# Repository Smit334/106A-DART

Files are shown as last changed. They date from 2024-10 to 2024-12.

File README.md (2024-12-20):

# 106A-DART

Our project aims to develop a transformable robotic vehicle that can transform from a car to a drone. It will achieve this by rotating the wheels 90 degrees and take flight using built-in propellers. It will be equipped with ultrasonic sensors to detect obstacles in its path, and navigate around them, either by maneuvering on the ground or flying over it. This innovative design offers the potential for enhanced mobility and versatility in various applications, such as search and rescue operations, exploration, and package delivery. 

## Repository Structure
- `docs`: writeups and presentations
- `ecad`: remote and vehicle PCB design files (Altium)
- `firmware`: remote and vehicle embedded code
- `mcad`: mechanical CAD, in .STEP format

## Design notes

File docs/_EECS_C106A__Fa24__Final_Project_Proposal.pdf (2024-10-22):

## EECS/BioE/MechE 106A/206A D.A.R.T: Driving And Rising Technology

Fall 2024

## 1 Team Information

Name | Background
Smit | Smit is a 4th year EECS major interested in Power Electronics, EV and Energy systems, electronics hardware design, and some firmware.
Amal | Amal is a 4th year EECS major interested in electronics and hardware design, pcb design, and robotics.
Nikhil | Nikhil is a 4th year EECS major interested in low-level programming, computerized systems infrastructure, and HV system design.
Andrew | Andrew is a 3rd Year Aerospace Engineering and EECS double major, interested in robotics, mechanical and electrical HW.
Mary | Mary is a 4th year EECS and Bioengineering double major interested in computer architecture and hardware design.

## 2 Abstract

Our project aims to develop a transformable robotic vehicle that can transform from a car to a drone. It will achieve this by rotating the wheels 90 degrees and take flight using built-in propellers. It will be equipped with ultrasonic sensors to detect obstacles in its path, and navigate around them, either by maneuvering on the ground or flying over it. This innovative design offers the potential for enhanced mobility and versatility in various applications, such as search and rescue operations, surveillance, and package delivery.

## 3 Project Description

### 3.1 Project Goals

What are your project goals?

- Successful Transformation: Develop a mechanism that allows the vehicle to reliably transform between car and drone configurations.
- Obstacle Detection and Avoidance: Implement an effective obstacle detection system using ultrasonic sensors to enable the vehicle to navigate around obstacles both on the ground and in the air through sensing and planning.
- Optimization: utilize weight-saving methods and implement power optimization to ensure the robot is as efficient as possible to maximize operation time.

### 3.2 Project Architecture

DART’s Hardware and Software systems will work together to meet project goals specified in section 3.1.

### 3.2.1 Software

- ROS: Using ROS Client/Server or Subscriber Publisher, to communicate sensor information to the micro controller to make high-level decisions for e.g if DART should be in drive mode or fly mode. And for the motor controllers to make more fine decisions like controlling power to each motor.
- Communication Protocols: We have the architecture for ROS setup as mentioned above but we will use some protocols to communicate this information on the firmware level. Some protocols we may use include:

– SPI
– I2C
– UART
– Analog and PWM
- Object detection libraries - to use information from the camera and Distance sensors to map objects and make decisions to avoid them.
- Autonomous and Remote Operation Modes

– Remote Operation: Radio-controlled mode will allow an operator to manually control the robot’s movement and transformation.
– Pre-programmed Path Execution: Users can define paths using way-points; the software will switch modes (drive/fly) as needed along the route
- Control Loops: PID Controllers will manage the speed of motors for smooth driving and flight stability

### 3.2.2 Hardware

The system will consist of the following subsystems

- Computing Subsystem: Responsible for coordinating and controlling other subsystems.

– Remote Operation: executes commands transmitted over the communication subsystem, interrupting them when necessary based on sensor subsystem feedback.
– Autonomous Operation: executes pre-programmed commands while reacting to feedback from the sensor subsystem.
- Power Distribution Subsystem: Responsible for ensuring sufficient power is provided to all subsystems when needed.
- Sensor Subsystem: Responsible for providing information about the robot’s local environment; detecting obstacles, mapping surroundings, etc. Consists of the following sensors:

– Digital Camera
– Distance Sensors
– IMU (Inertial Measurement Unit)
- Communication Subsystem:

– Remote Operation: Receives command inputs, transmits sensor information and other subsystem data.
– Autonomous Operation: Transmits sensor information, and other subsystem data.
- Flying Subsystem: Consists of a set of 4 motors in a quad-copter configuration. Works with the computing subsystem and sensor subsystem to fly in the air.
- Driving Subsystem: Consists of a set of 4 motors to drive on the ground.
- Transformation Subsystem: Responsible for transitioning between the flying and driving configurations of the robot.

### 3.3 Project Sensing, Planning, and Actuation

How does your project incorporate sensing, planning, and actuation?
Sensing:
- Drive Mode: Sensors like LiDAR or ultrasonic sensors will be used to detect obstacles, focusing on the vertical axis in front of the robot. These sensors will determine the height of obstacles and detect when they become unavoidable.
- Flight Mode: The same sensors will monitor the height and proximity of obstacles, determining how high the drone needs to fly to clear them. Additionally, these sensors will identify when the obstacle has been cleared, allowing the robot to safely return to the ground. Sensors will monitor the terrain below during flight to detect when it is safe to land (e.g., flat surface or low obstacle height).

Planning:

- Drive Mode: The robot will follow a pre-specified path or respond to remote control inputs for direction. While navigating, the robot will analyze the sensor data to detect obstacles in its path. If an obstacle is too tall to drive over or around, the robot’s planning system will trigger a transition to flight mode.
- Flight Navigation: The planning system will use obstacle height data to calculate the necessary altitude for the drone to fly over the obstacle safely. The system will continuously monitor the vertical space until it senses that the obstacle has been passed and there’s a clear landing zone. Once the planning system detects that the obstacle is behind the robot and that it can safely descend, it will initiate the transition back to drive navigation, allowing the robot to resume following the path or remote control directions.

Actuation:

- Drive Mode: The robot’s drive motors will actuate based on planned paths or remote control inputs. When the system senses an unavoidable obstacle, the robot will stop moving, preparing for transition into flight mode.
- Flight Mode: The robot will actuate propeller motors to take off and adjust its altitude based on the calculated obstacle height. The actuation system will maintain flight until the obstacle is passed, at which point the descent will be triggered. The actuation system will control the drone’s descent once the terrain below is deemed safe for landing, switching back to drive mode.

### 3.4 Project Tests and Metrics

How will you test or assess your project? What constitutes a success? What are some realistic goals? What are some reach goals?
This project is intended as mainly a proof-of-concept. That is, a successful project will involve basic testing of the robot’s core functions. Enumerated, these are:
- Motor control: Drive all motors simultaneously at varying speeds using the MCU. This validates the motors are functional, the MCU can send commands, and the power delivery system to the motors is adequately sized.
- Communication: Drive one or more motors over the radio control system, testing the radio. Repeat this test for multiple ranges to find a maximum radio communication distance.
- Basic driving: The robot drives a short distance without flying, from commands issued through the radio controller.
- Basic flying: The robot flies a short distance (take off, hover, rotate, directional translation, and landing) without driving from commands issued through the radio controller.

- Drive → Fly transition: Start by driving, transition to flying, and end by flying.
- Fly → Drive transition: Start by flying, transition to driving, and end by driving.
- Pre-programmed path execution: Send a path to the vehicle from the base station with instructions to drive/fly a certain distance, then execute those instructions with reasonable accuracy.
- Driving with sensing: Drive with automatic object avoidance
- Flying with sensing: Fly with automatic object avoidance

These are all reasonable goals which should be able to be completed within the given time window. A stretch goal would be to implement an automatic fly/drive transition feature, where the vehicle could transform from flying to driving mode (or vice versa) based on the environment in order to avoid obstacles. A test for this may be a set of stairs, in which the vehicle would detect the stairs and transition to flying mode to avoid said stairs by going over them.

## 4 Tasks

Here, list out different major and minor tasks of the project, along with when you plan to achieve them. Keep in mind the checkpoint dates (11/9 and 11/29). For example,

1. Build the robot
(a) Design the Robot [by 11/2]
i. Design the Robot Frame [by 11/2]
A. Design the Transformation Subsystem Emphasis is put on ensuring a sound transformation system is designed, other parts of the frame are dependent this design.[by 11/1]
B. Design Other Robot Structural Components Ensure the system is structurally sound in both modes of operation, plan out the placement of electronics. [by 11/1]
ii. Design the Robot Electronics [by 11/2]
A. Select Necessary Parts Spec out the exact components used for the robot, crucial to determining other aspects of design. [by 10/26]
B. Design the Central PCB Based on component specifications, incorporate Power Distribution, Computing, Communication, and Sensor subsystems onto a unified PCB. [by 11/2]
(b) Assemble the Robot [by 11/11]
i. If any issues are encountered in this stage, rapid prototyping will modify the design.
2. Code the robot. We will program the robot using C++, Python, Arduino
(a) Develop firmware for peripherals listed below [by 11/6]
i. IMU
ii. Motor controller
iii. Servo controller
iv. Camera and Distance sensors
(b) Develop ROS Nodes : Controller and sensor nodes to broadcast information [by 11/13]
(c) Develop Software/firmware for controlling DART in Remote mode [by 11/25]
(d) Object detection and path planning algorithm: Working in parallel to Firmware development to design the autonomous planning. [by 11/25]
3. Testing

(a) Hardware Validation Ensure all the hardware is working as expected, without direct software control from intended controller system [by 11/17]
(b) Software Validation Ensure software is functioning without intended hardware system (HIL testing or similar) [by 11/25]
(c) Integration Testing Integrate software and hardware together, and perform tests as described in the "Testing" section [by 12/2]
(d) Stretch Goals Implement anything additional and perform tests for those features [by 12/3]

## 5 Bill of Materials

### 5.1 Use of Lab Resources

This project will largely be constructed without lab resources. However, if possible we would like to request a LiDAR and/or lightweight near field sensing camera of some kind if possible.

Item | Quantity
LiDAR / lightweight camera | 1

### 5.2 Other Robotic Platforms

We do not have access to any other external robotic platforms (nobody in our group is a member of a robotics-related lab).

### 5.3 Other Purchases

The majority of components for this project will need to be purchased. We expect this will exceed the $60 budget, but understand that we will be responsible for covering the remainder of the purchases. The total estimated project budget is ≈$100.
Components are listed as general categories to best communicate the types of items required. Note that specific part numbers will be collated for submission in the ESG form (up to the $60 amount).
Item | Quantity | Justification
Fly Motors | 4 | Brushless DC (BLDC) motors to drive the propellers to create flight
Drive Motors | 4 | BLDC motors to drive the wheels to enable motion on the ground
Battery | 1 | LiFePo4 sized to power fly/drive motors, sensors, servos, and MCU
Radio Transceivers | 2 | Communicate between vehicle and base station (controller)
Servos | 4 | Adjust wheels from flying ⇐⇒ driving
Wiring | N/A | Harnessing for tying everything together
PCB | 1 | Mainboard for logic controllers to simplify harnessing
Microcontroller (MCU) | 1 | Main logic controller (Ardunio/Teensy)
Inertial Measurement Unit (IMU) | 1 | Orientation and gyroscope for flight
Motor Controllers | 8 | Drives motors with output from MCU
Ultrasonic Sensors | 4-8 | Distance sensing for each side; octagonal approximation
FPV Camera (optional) | 1 | If weight allows, add for human sight
Frame Materials | N/A | 3D printed frame out of PETG or PLA
Wheels | 4 | Enables motion; 3D printed wheels out of TPU
Propeller | 4 | Enables lift

## 6 Other

This section contains all additional information necessary to convince us that a) you are equipped to complete the project you propose, and b) you have thought specifically about your project implementation. This section is optional, but some things you might mention include:

- ROS packages you’ll need (with pointers to relevant websites);
- preliminary code structure/skeleton; and
- mechanical designs/drawings/sketches of your project.

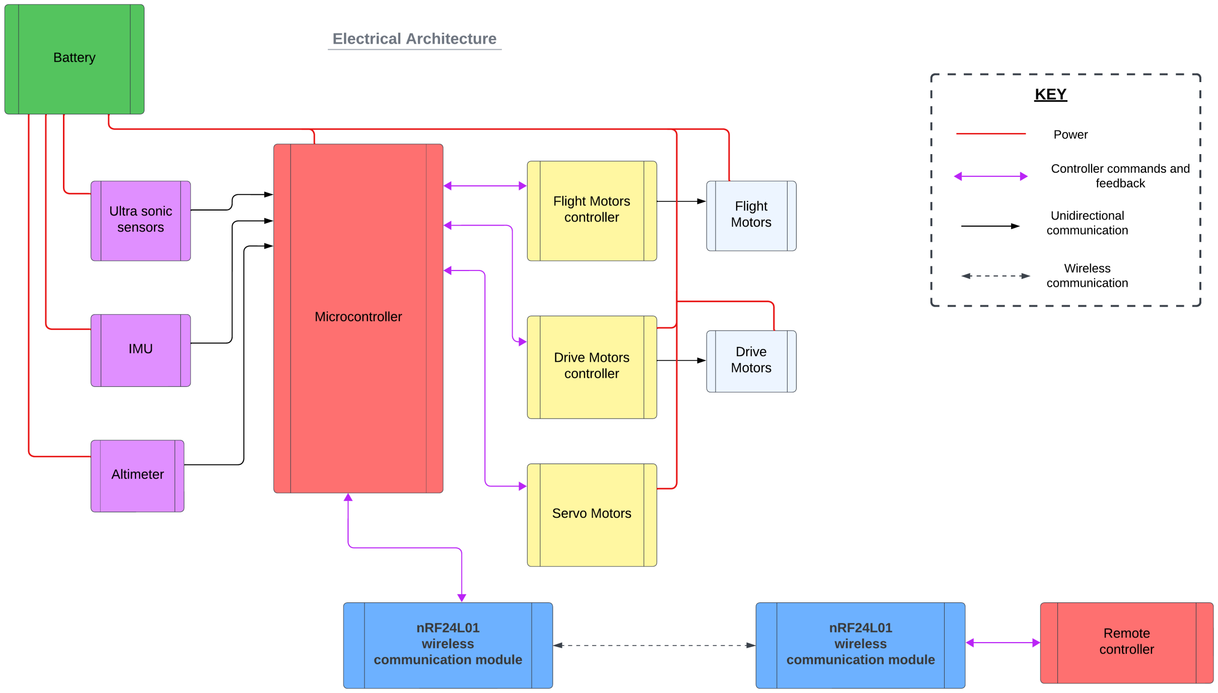
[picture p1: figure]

Figure 1: Electrical Architecture

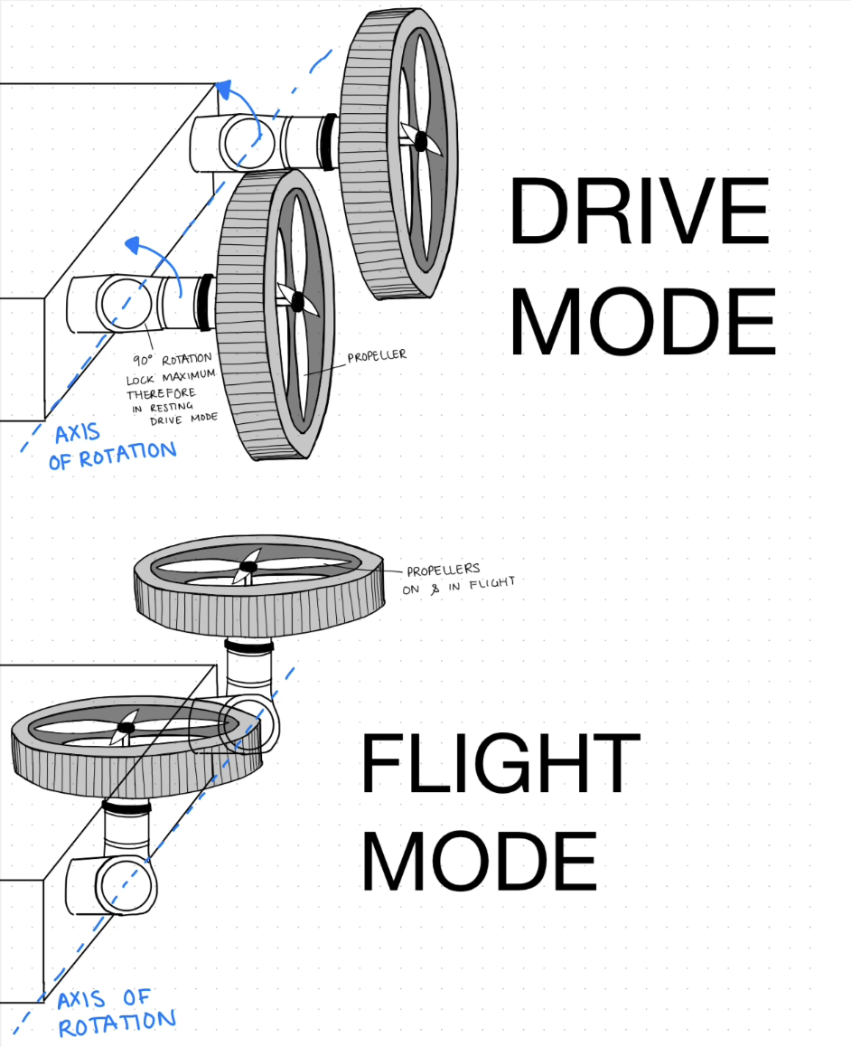
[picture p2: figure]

Figure 2: Drive Mode vs Flight Mode Joint Positions

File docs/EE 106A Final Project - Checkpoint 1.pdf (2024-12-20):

EECS C106A Final Project Check-In 1 D.A.R.T (Team 27)
Nikhil, Smit, Amal, Andrew, Mary

## Original Abstract

Our project aims to develop a transformable robotic vehicle that can transform from a car to a drone. It will achieve this by rotating the wheels 90 degrees and take flight using built-in propellers. It will be equipped with ultrasonic sensors to detect obstacles in its path, and navigate around them, either by maneuvering on the ground or flying over it. This innovative design offers the potential for enhanced mobility and versatility in various applications, such as search and rescue operations, surveillance, and package delivery.

## Updates

Since receiving feedback on our project design, we have been hard at work prototyping and creating designs for our vehicle. Namely, we have split up the project into three main components: mechanical, electrical, and software. All three have been substantially developed and are on track to be completed by the project deadline.

See following pages for more details.

### Mechanical

The mechanical portion is the most critical portion to the success of the vehicle, and we have made excellent progress so far. We have prototyped a toroidal propeller design which will enable us to have enough lift to ascend off the ground while still enabling smooth driving. This design has been honed through multiple revisions, utilizing the rapid development capabilities of 3D printing. To test the amount of lift being generated, we have also designed a thrust measurement device which sets up the motor-propeller system to push against a kitchen scale (through an intermediate beam).

We have also developed a driving gear mechanism which will propel the car whilst on the ground. This includes optimizations for weight savings, as since this is a drone the lighter the craft, the easier it will be to fly. Again, these designs continue to be iterated upon and show promising results in preliminary integration testing. Images of all these developments are shown below.

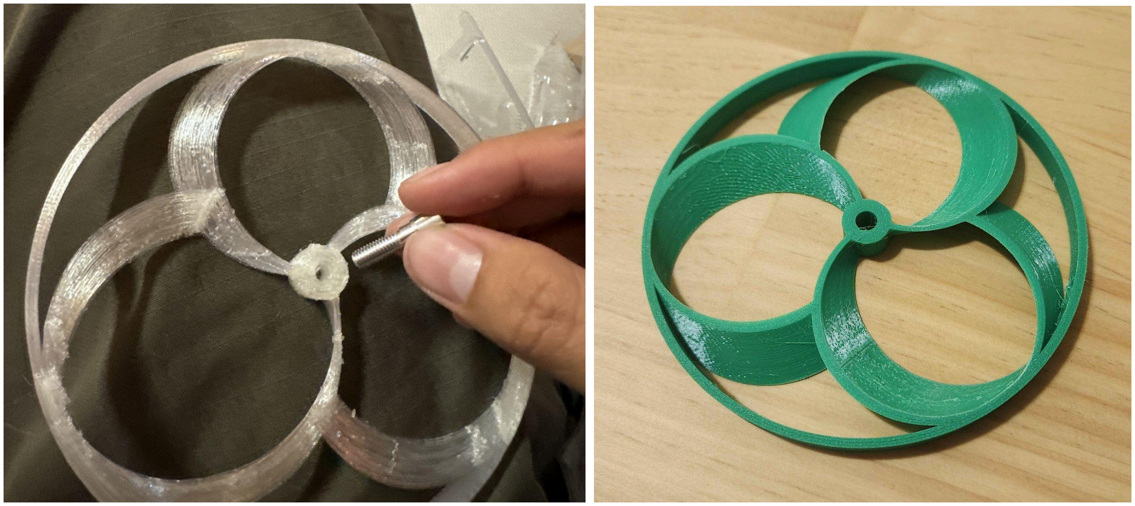
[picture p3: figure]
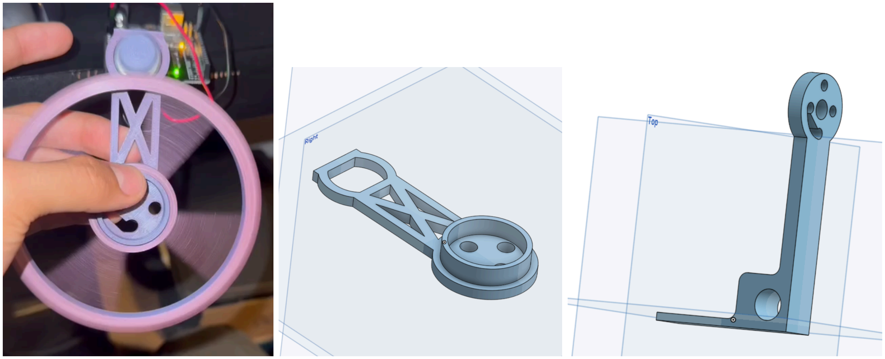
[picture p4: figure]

### Electrical

To enable the mechanical functions of the vehicle, we have designed two Printed Circuit Boards (PCBs). One will be placed onto the drone and handle all flight (and drive) control logic and be powered by a Teensy 4.1. The other is a remote control which will send signals to the receiver, powered by an Arduino Pro Micro. We have just recently sent these to be manufactured at JLCPCB (this purchase is not covered by the course-provided budget). Images of the completed boards can be seen below.

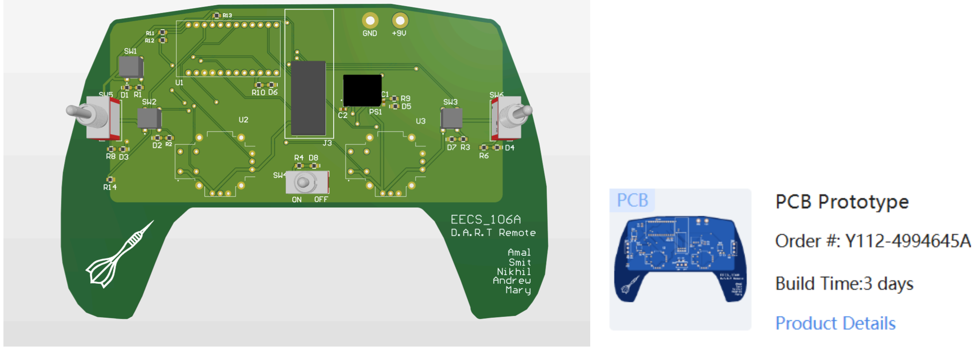
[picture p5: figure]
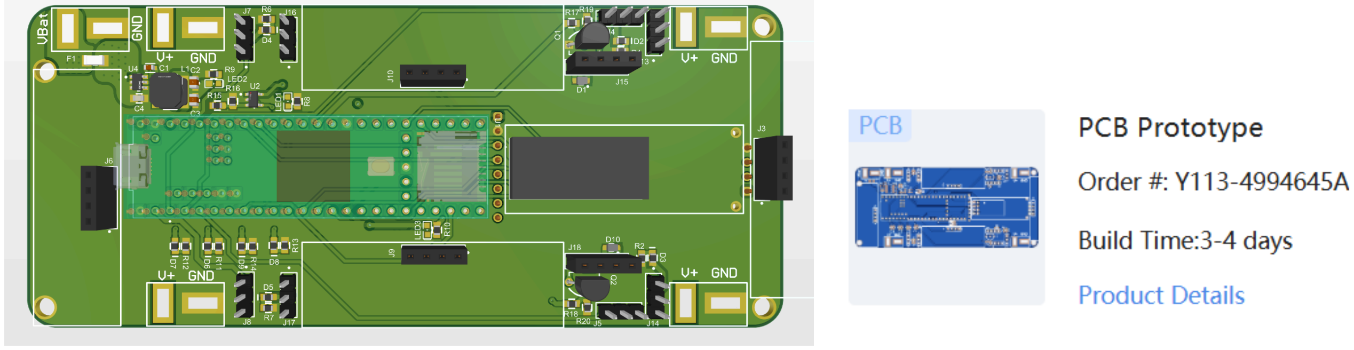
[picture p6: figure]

### Software

All flight and drive controller logic has been implemented in C, and is ready to be tested. All code is version-controlled in a private repository. Much of the code borrows from the principles described in dRehmFlight, (https://github.com/nickrehm/dRehmFlight) an open-source flight controller intended to be used with VTOLs.

Much of the software work so far has been to validate functionality of individual components. For example, we are using brushless DC (BLDC) motors, which require special electronic speed controllers (ESCs). These in turn require specific pulse widths to be sent to them in a specific sequence; which itself is poorly documented. We found that a 1.5-2ms pulse is required. Although frequency-independent, a maximum frequency of 490Hz is desired. This is because on Teensy/Arduino, PWM can be driven by an integer value in the range of 0 to 255 (inclusive). At 490Hz, 255 corresponds to maximum power (2ms pulse), thus not requiring additional high-side scaling. The low-side (1.5ms pulse) therefore corresponds to a PWM value of 175, reducing range to 80 integers. This is not specified in any datasheet, and we have had to test these extensively.

We also have tested our ultrasonic sensors and determined that they are quite noisy, especially with soft/ridged surfaces. To mitigate this, we tested different digital filtering methods and settled on a moving average filter. Pictures of this testing can be seen below.

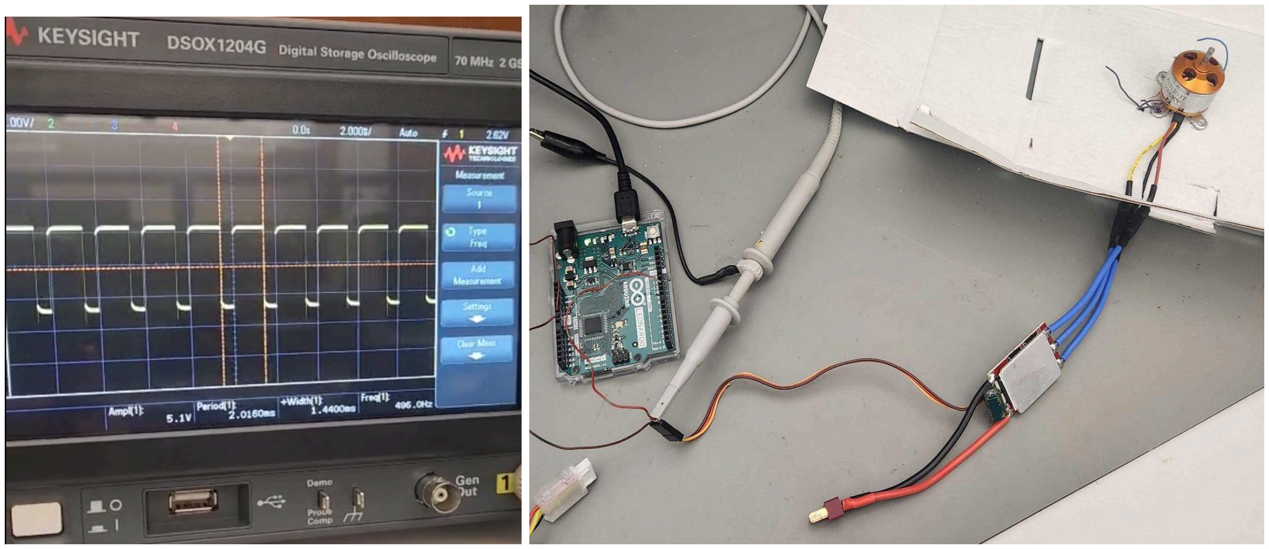
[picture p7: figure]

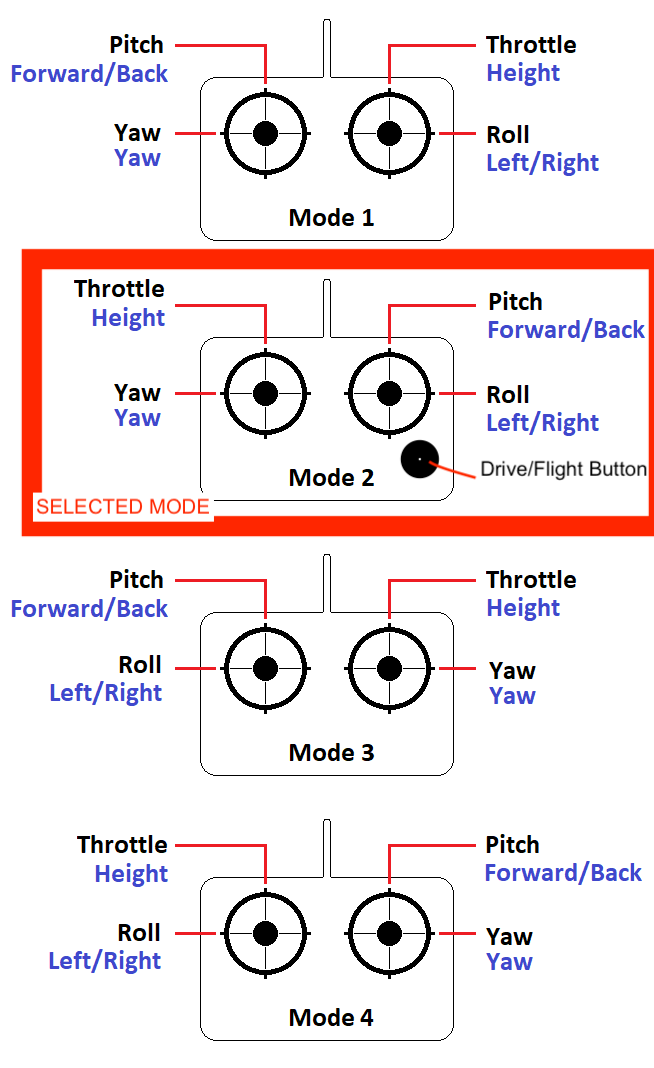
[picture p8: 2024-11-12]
firmware/remote/flightcontrols.png

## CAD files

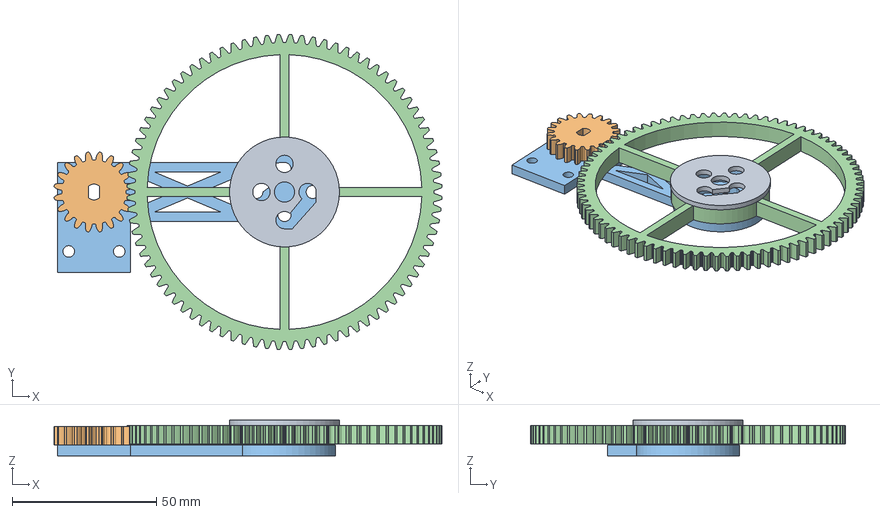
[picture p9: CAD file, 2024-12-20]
mcad/Assembly 2.step
134.5 x 109.2 x 12.3 mm
Spur gear (20 teeth)
Spur gear (84 teeth)

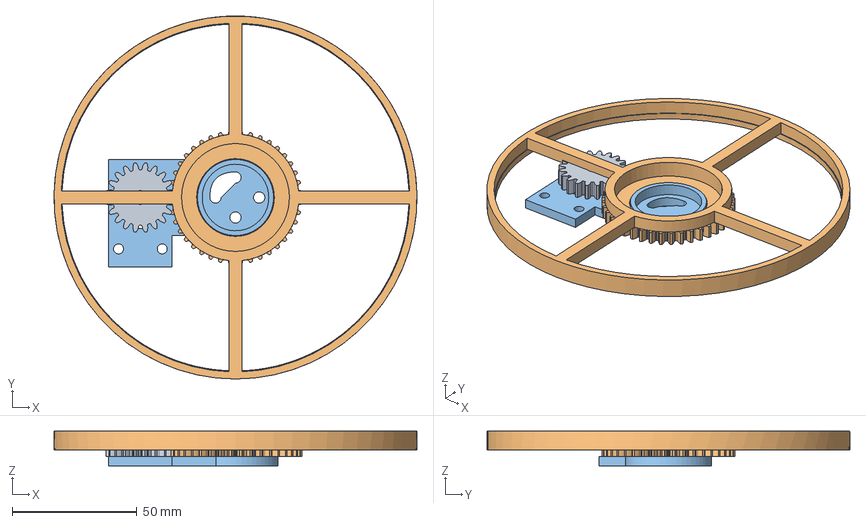
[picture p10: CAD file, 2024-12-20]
mcad/Assembly 3.step
145.4 x 145.4 x 14.0 mm
Spur gear (20 teeth)
Spur gear (40 teeth)

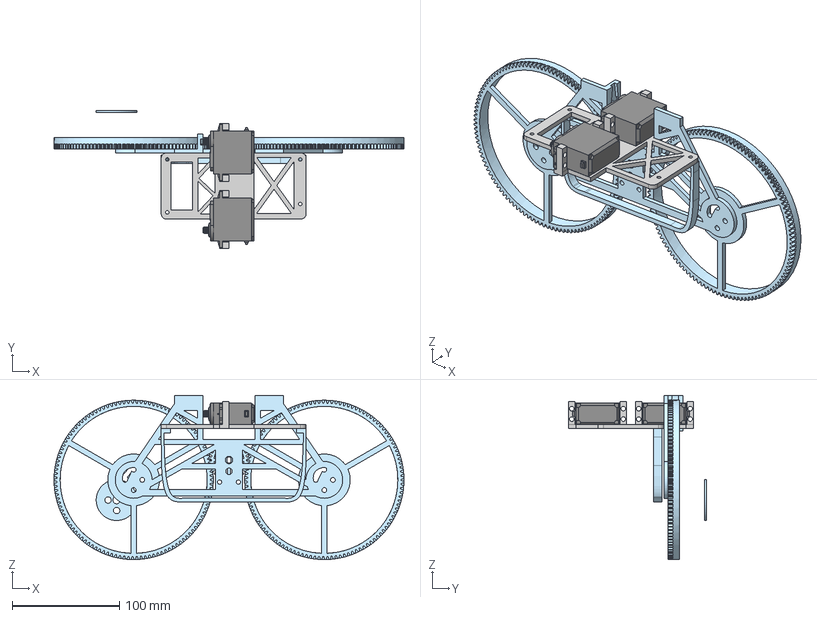
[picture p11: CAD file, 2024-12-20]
mcad/Assembly 6.step
326.4 x 128.5 x 153.0 mm
MG995 v3 x 4
Spur gear (28 teeth)
Spur gear (115 teeth) x 2

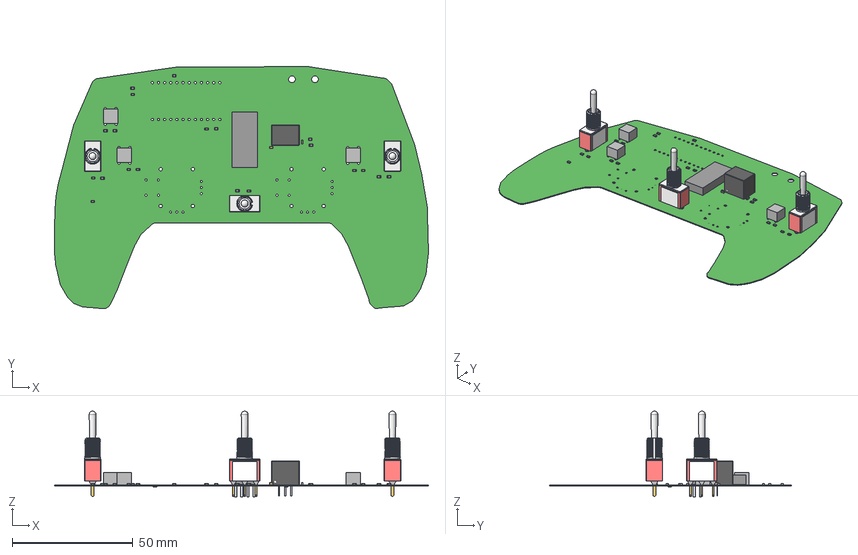
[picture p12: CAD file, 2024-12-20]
ecad/STEP_[No Variations] for Remote.PcbDoc.step
154.8 x 100.1 x 35.5 mm
Extruded x 69
capacitor 0603 x 2
Leads
c-4-1825136-4-a-3d x 3
TE connectivity Logo 1 (2) x 3

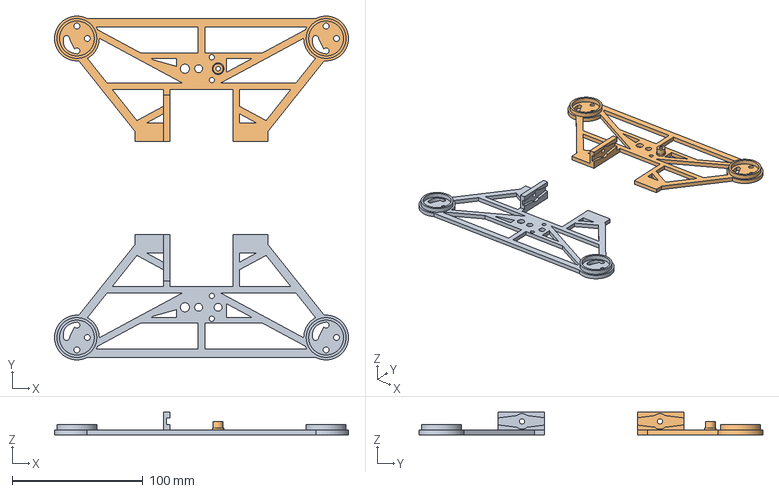
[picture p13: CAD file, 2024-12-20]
mcad/Reduced moment Copy 1.step
224.7 x 262.9 x 17.5 mm

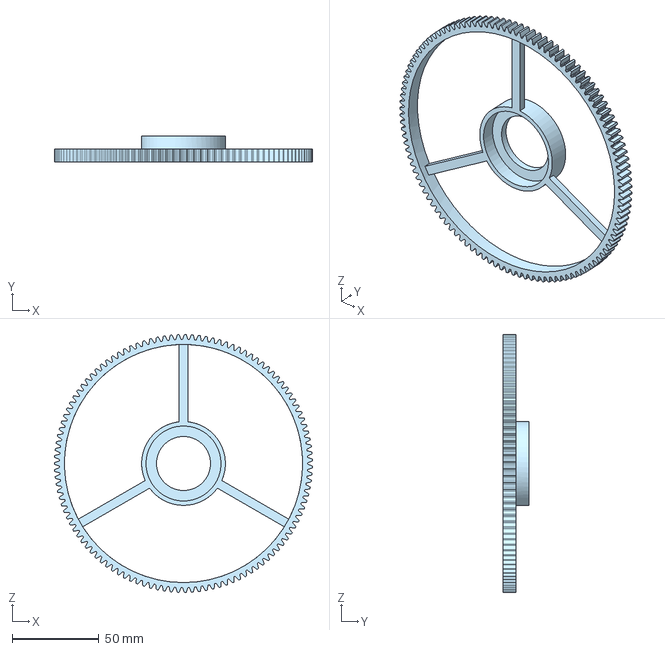
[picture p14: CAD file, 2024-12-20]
mcad/driving gear v2 Copy 1.step
148.6 x 15.2 x 148.6 mm

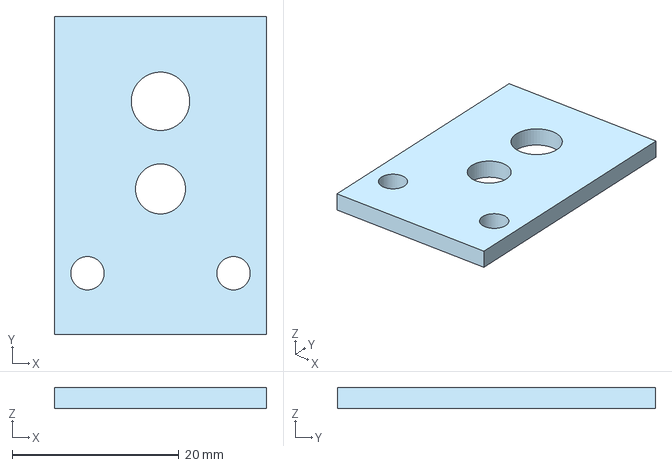
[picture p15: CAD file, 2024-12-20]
mcad/drivingmotorsizing.step
25.4 x 38.1 x 2.54 mm

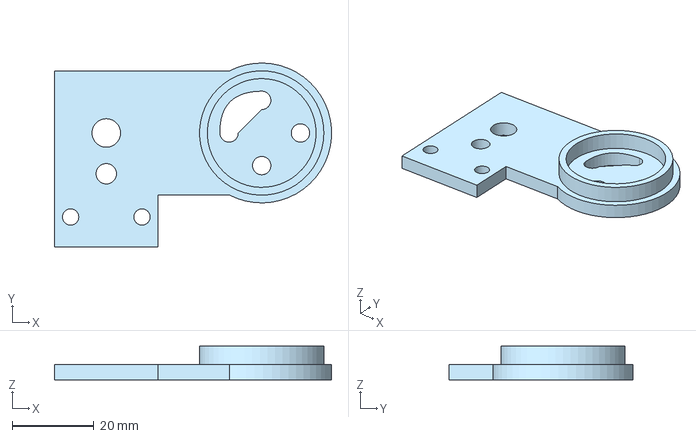
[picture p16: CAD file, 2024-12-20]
mcad/Part Studio 3.step
67.9 x 45.1 x 8.26 mm

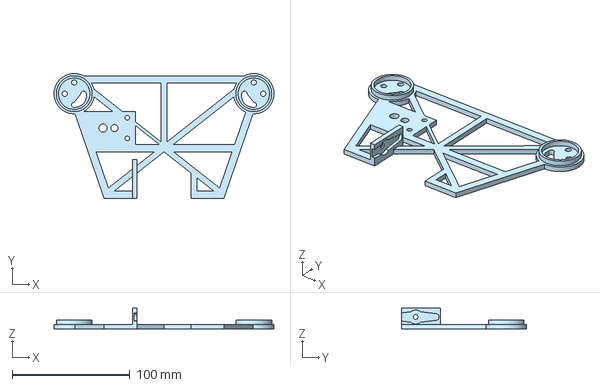
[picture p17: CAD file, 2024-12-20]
mcad/Part Studio 4.step
186.7 x 106.0 x 17.5 mm

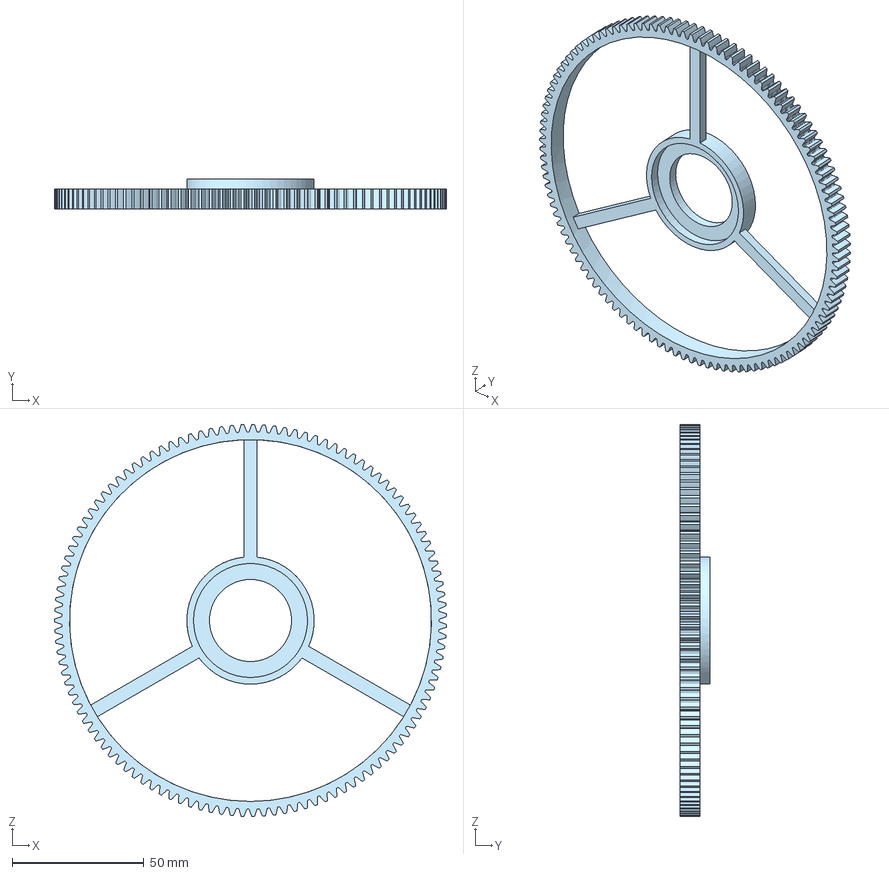
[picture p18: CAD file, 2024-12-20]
mcad/driving gear v2 Copy 2.step
148.6 x 11.4 x 148.6 mm

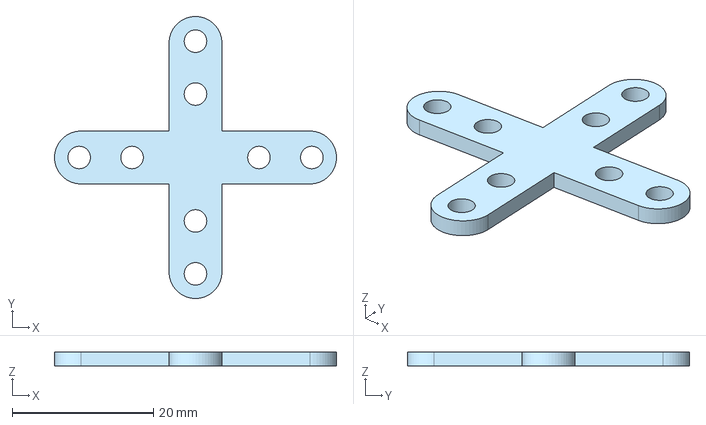
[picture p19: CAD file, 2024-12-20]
mcad/motor bracket.step
40.0 x 40.0 x 2.00 mm

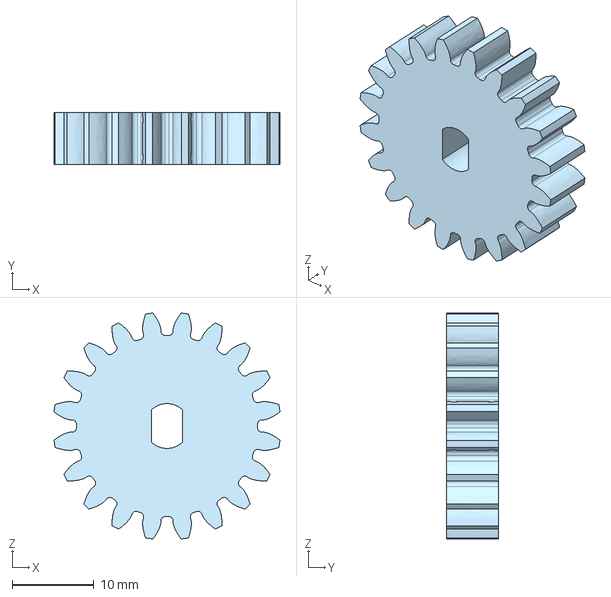
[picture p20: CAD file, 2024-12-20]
mcad/MotorGear.step
27.7 x 6.35 x 27.7 mm

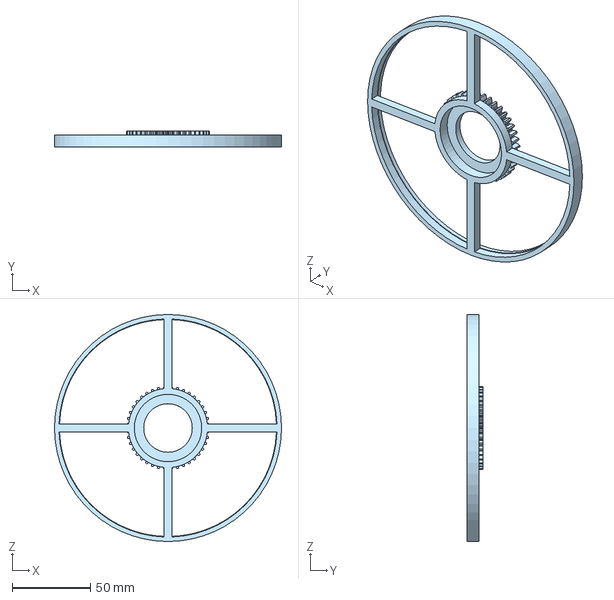
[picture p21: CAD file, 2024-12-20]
mcad/drivinggear Copy 1.step
145.4 x 10.2 x 145.4 mm

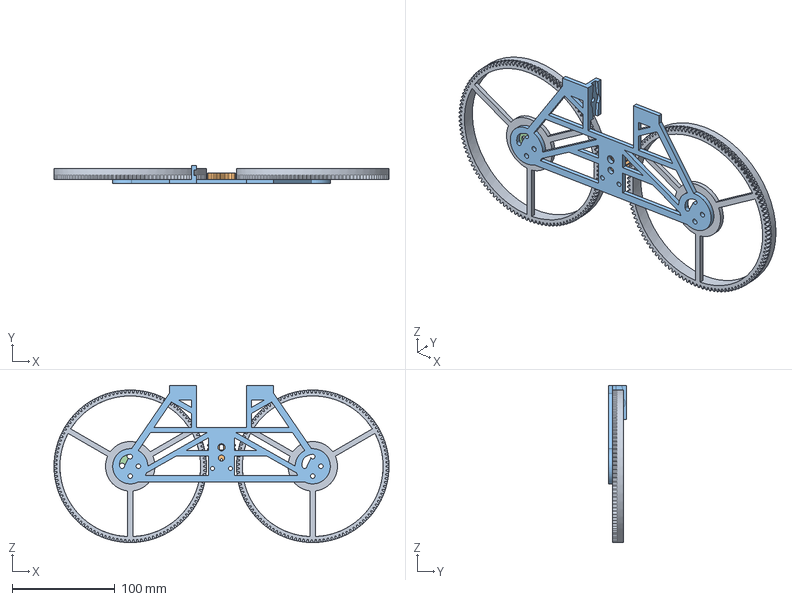
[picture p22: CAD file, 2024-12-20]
mcad/RightSideAssem.step
326.4 x 17.5 x 153.0 mm
Spur gear (115 teeth) x 2
Spur gear (20 teeth)

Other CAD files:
mcad/MotorGearDrive2.step
mcad/refactored driving motor Copy 1.step
mcad/arm mockup.step
mcad/Servo Motor Horn.step
mcad/Torodial Proppellor.step
mcad/Wheel.step
mcad/driving gear (improved grip).step
mcad/tinyendcap.step

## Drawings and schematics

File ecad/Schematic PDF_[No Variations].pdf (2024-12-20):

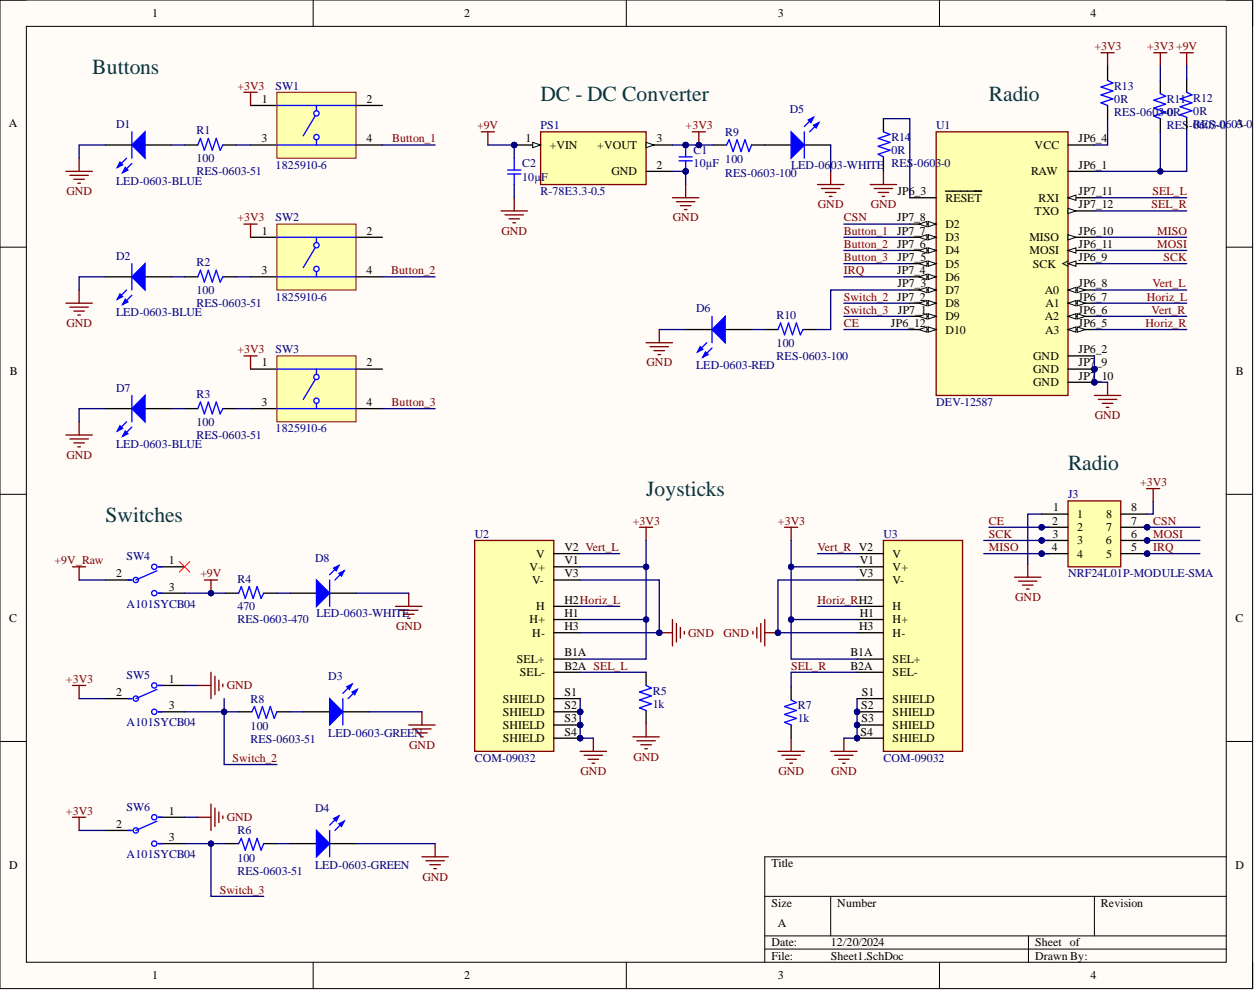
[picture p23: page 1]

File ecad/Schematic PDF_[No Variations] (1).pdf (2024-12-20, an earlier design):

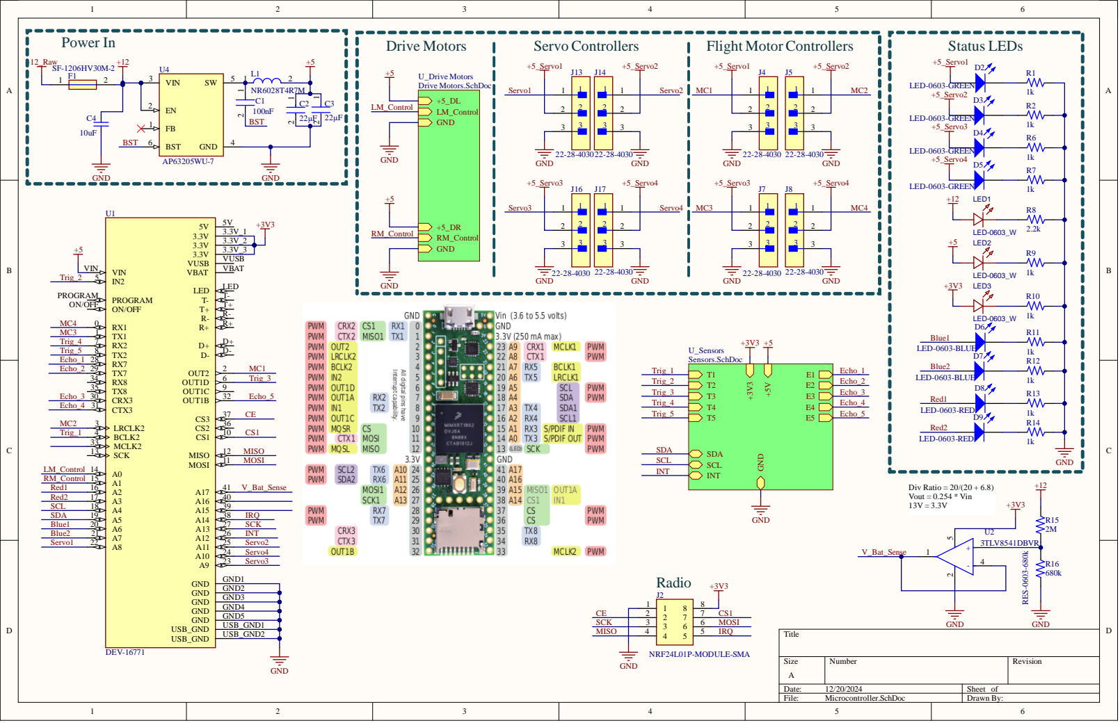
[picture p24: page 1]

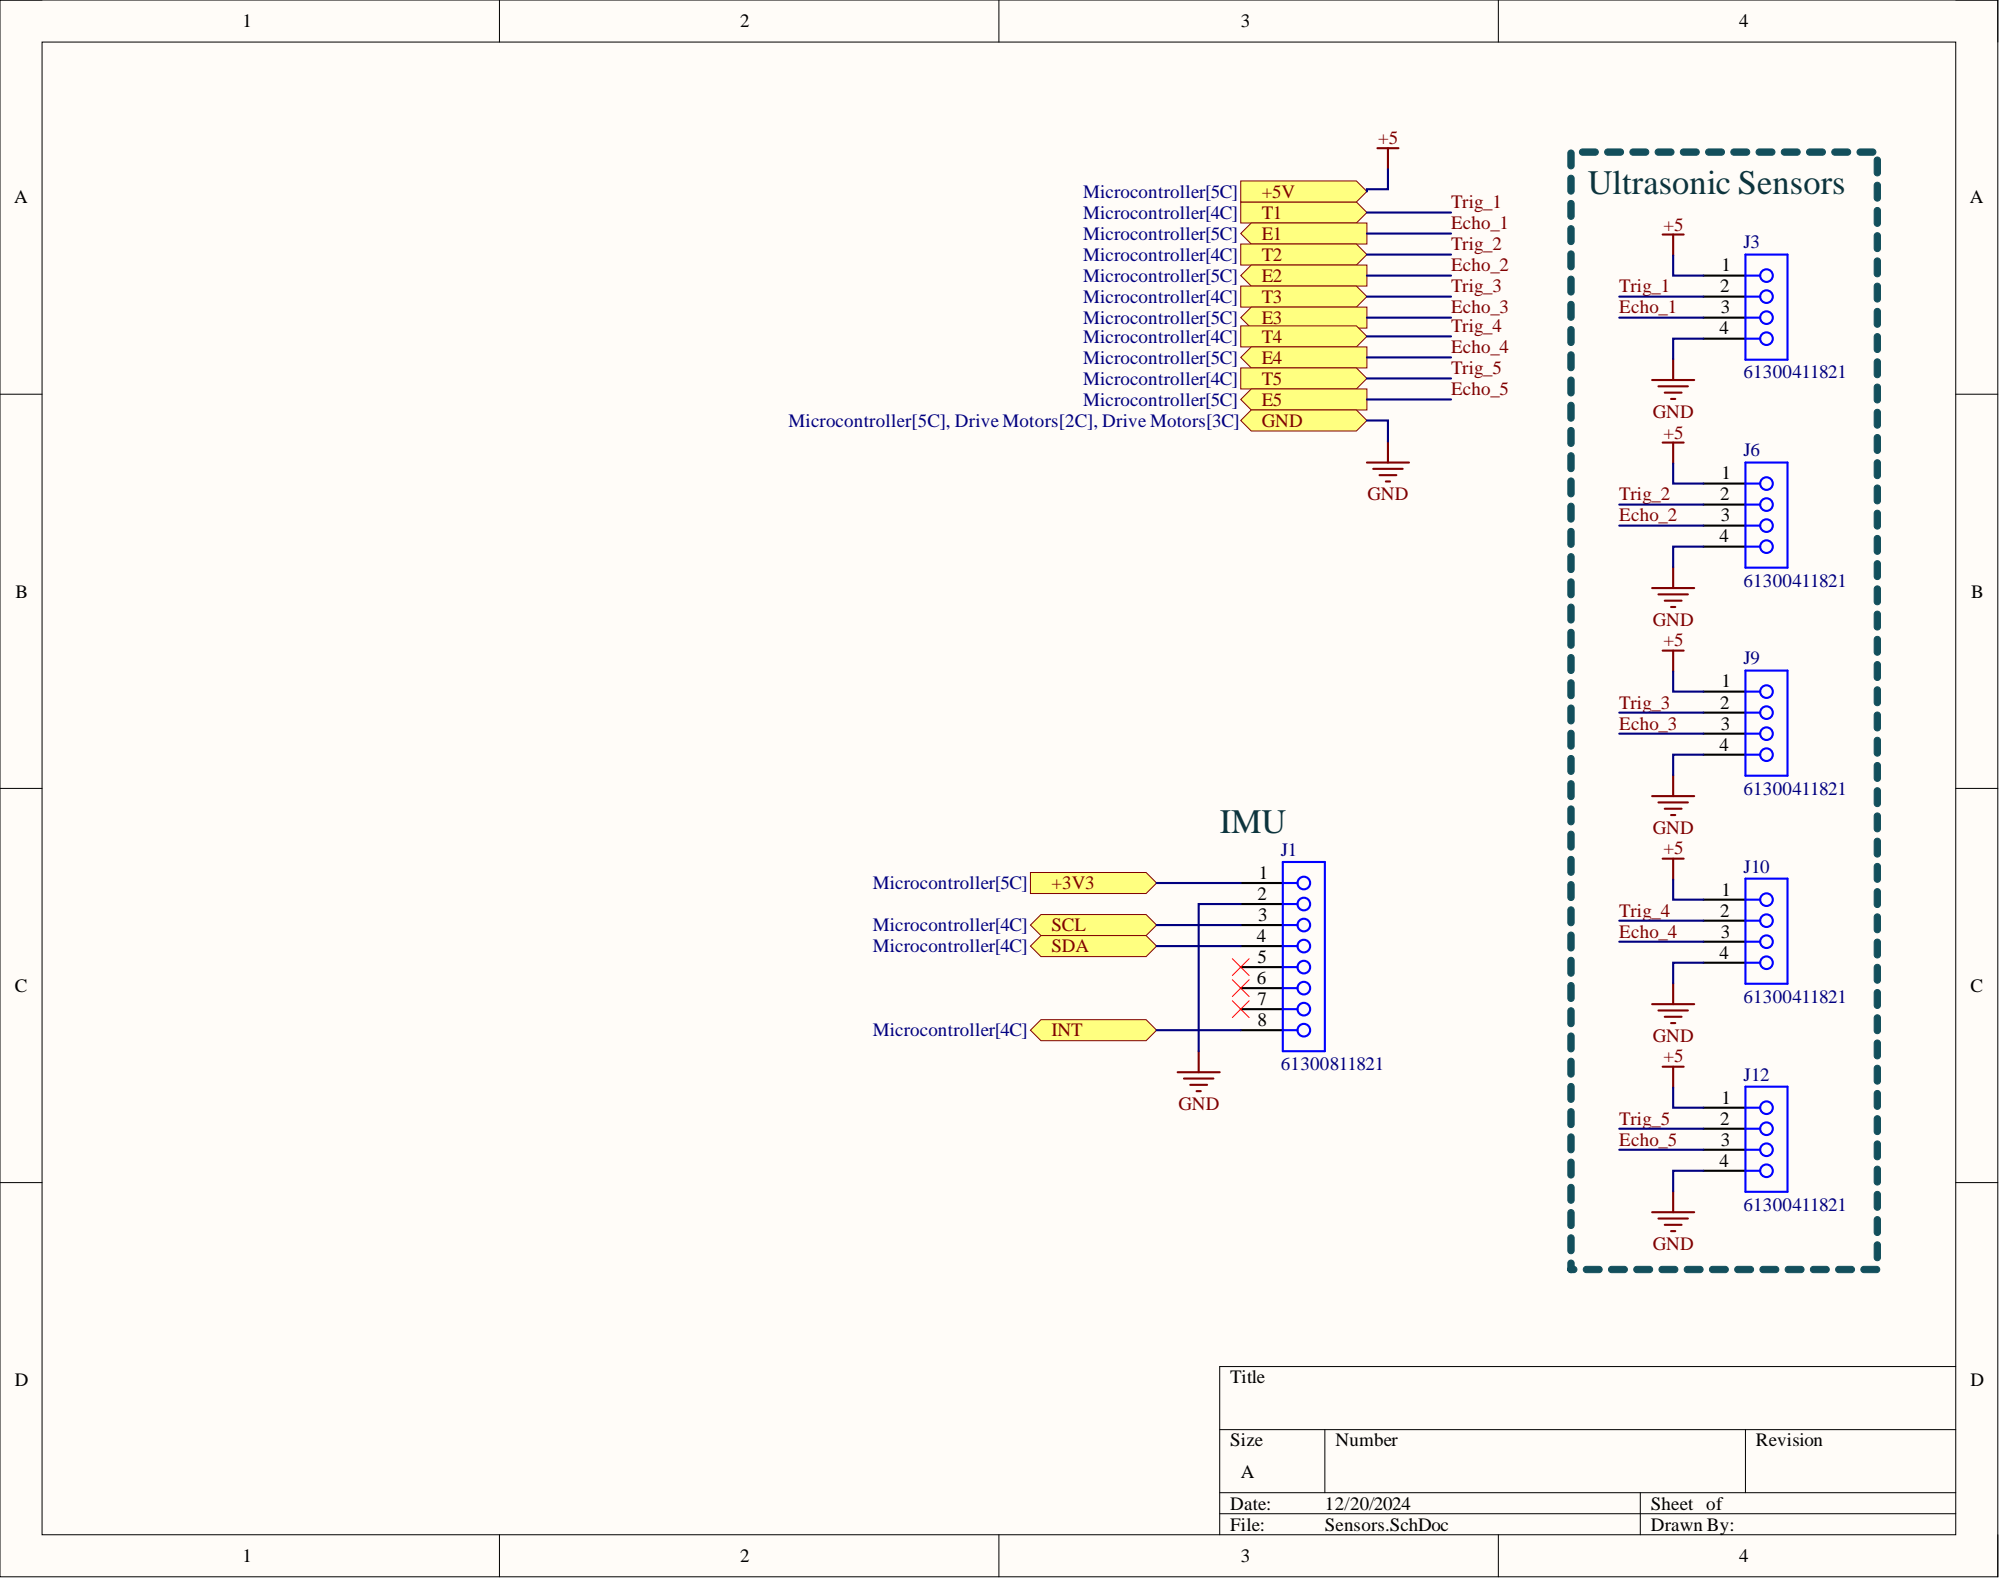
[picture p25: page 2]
Date:; Sheet of; File:; Sensors.SchDoc; Drawn By:; Ultrasonic Sensors; Trig_4 Echo_3; Microcontroller[5C]; E3 Microcontroller[4C]; Microcontroller[5C], Drive Motors[2C], Drive Motors[3C]; GND; NLEcho03 POE3; NLEcho05 POE5; NLTrig01 POT1; NLTrig03 POT3; NLTrig05 POT5

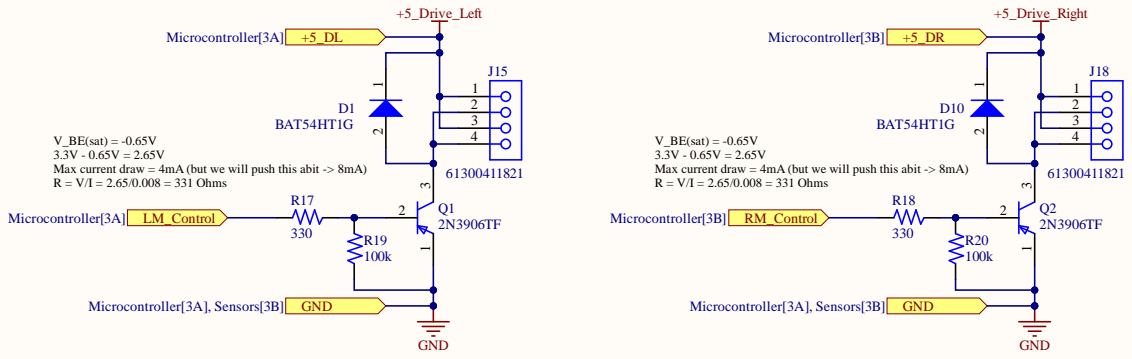
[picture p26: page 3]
A (but w; l push thi; s abi; /I = 2.65/0.008 = 331 Ohm; A], Sen

3.3V - 0.65V = 2.65V Max current draw = 4m

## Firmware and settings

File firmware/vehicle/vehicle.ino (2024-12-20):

#include <Wire.h>
#include <SPI.h>
#include <nRF24L01.h>
#include <RF24.h>
#include <Servo.h>

#include "sensors.h"
#include "attitude_estimator.h"

extern "C" {
  #include "util.h"
  #include "flightController.h"
  #include "driveController.h"
}

IMUData imuData;
IMUData imuError;
float ultrasonicCentimeters[NUM_US];
// AttitudeEstimator position;
RPYAngles position;
RPYAngles pid;
DriveCommands driveCmds;
DriveCommands nullDriveCmds = {};
FlyCommands flyCmds;
FlyCommands nullFlyCmds = {};

RadioPacket packet;
float throttle;
RPYAngles des;
vehicle_mode_t lastVehicleMode;
bool isEmergencyStopped;
unsigned long radioRxStartTime;
uint32_t autoFlightStartTimeMs;

RF24 radio(RADIO_CE_PIN, RADIO_CSN_PIN);
Servo transitionServos[NUM_TSERVO];
Servo flyMotorServos[NUM_FLY_MOTORS];

void setup() {
  Serial.begin(115200);

  initConstants();

  /* Initialize I2C */
  Wire1.begin();
  Wire1.setSCL(I2C_SCL);
  Wire1.setSDA(I2C_SDA);
  Wire1.setClock(1000000);

  /* Initialize IMU (over I2C) */
  initIMU(&Wire1);

  /* Initialize SPI */
  SPI.begin();

  /* Initialize radio (over SPI) */
  radio.begin();
  radio.setPALevel(RF24_PA_HIGH);
  radio.setChannel(RADIO_CH);
  radio.openReadingPipe(1, RADIO_ADDR);
  radio.startListening();

  /* Initialize pin modes for fly motors. */
  for (uint32_t ch = 0; ch < NUM_FLY_MOTORS; ++ch) {
    flyMotorServos[ch].attach(FLY_MOTOR_PINS[ch]);
    analogWriteFrequency(FLY_MOTOR_PINS[ch], PWM_FREQ_HZ);
  }

  /* Initialize pin modes for drive motors. */
  for (uint32_t ch = 0; ch < NUM_DRIVE_MOTORS; ++ch) {
    pinMode(DRIVE_MOTOR_PINS[ch], OUTPUT);
    analogWriteFrequency(DRIVE_MOTOR_PINS[ch], PWM_FREQ_HZ);
  }

  /* Initialize pin modes for ultrasonic sensors. */
  for (uint32_t ch = 0; ch < NUM_US; ++ch) {
    pinMode(US_TRIG[ch], OUTPUT);
    pinMode(US_ECHO[ch], INPUT);
  }

  /* Create and attach Servo objects to servo pins. */
  for (uint32_t ch = 0; ch < NUM_TSERVO; ++ch) {
    transitionServos[ch].attach(TRANSITION_SERVO_PINS[ch]);
    analogWriteFrequency(TRANSITION_SERVO_PINS[ch], PWM_FREQ_HZ);
  }

  /* Debug / LED pins */
  pinMode(LED_BLUE_A_PIN, OUTPUT);
  pinMode(LED_BLUE_B_PIN, OUTPUT);
  pinMode(V_BAT_PIN, INPUT);

  setServos(FLIGHT_MODE);
  lastVehicleMode = FLIGHT_MODE;

  currTime = micros();
  trackLoopTime();

  Serial.println("START CALIBRATION");
  // calibrateAttitude();
  // position.setMagCalib(0, 0, 0);
  calibrateIMU(&imuError);
  Serial.println("END CALIBRATION");
}

void calibrateAttitude() {
  uint32_t i;
  for (i = 0; i < NUM_IMU_CALIBRATION_ITER; ++i) {
    trackLoopTime();
    readIMU(&imuData);
    Madgwick6DOF(&imuData, &position);
    limitLoopRate();
  }
}

uint32_t loopCtr = 0;

void loop() {
  trackLoopTime();

  readIMU(&imuData);
  subIMUData(&imuData, &imuError);
  // printIMU(&imuData);
  // Madgwick6DOF(&imuData, &position);
  // position.update(dt, imuData.accX, imuData.accY, imuData.accZ, deg2rad(imuData.gyrX), deg2rad(imuData.gyrY), deg2rad(imuData.gyrZ), 0, 0, 0);
  // if (loopCtr % 100 == 0) {
    // Serial.print("PYAW ");
    // Serial.println(position.yaw);
    // Serial.print("PPITCH ");
    // Serial.println(position.pitch);
    // Serial.print("PROLL ");
    // Serial.println(position.roll);
  //   Serial.print("LOOP TIME ");
  //   Serial.println(dt*1e6);
  // }
  // loopCtr++;

  // Serial.print("PYAW ");
  // Serial.println(position.eulerYaw());
  // Serial.print("PPITCH ");
  // Serial.println(position.eulerPitch());
  // Serial.print("PROLL ");
  // Serial.println(position.eulerRoll());

  // Serial.println(radio.isChipConnected());
  // ultrasonicCentimeters[US_FRONT_IDX] = usToCentimeters(readUltrasonicAveraged(US_FRONT_IDX));
  // Serial.println(ultrasonicCentimeters[US_FRONT_IDX]);
  
  displayDebugIndicators();
  radioRxStartTime = millis();
  while ((!radio.available() || !radio.isChipConnected()) && !isEmergencyStopped) {
    if ((millis() - radioRxStartTime) > RADIO_RX_TIMEOUT_MS) {
      isEmergencyStopped = true;
      break;
    }
  }
  radio.read(&packet, sizeof(packet));
  // printPacket(&packet);
  // Serial.println(usToCentimeters(readUltrasonicAveraged(US_FRONT_IDX)));
  if (packet.buttonThree || isEmergencyStopped) {
    isEmergencyStopped = true;
    digitalWrite(LED_BLUE_B_PIN, HIGH);
    clearFlightMotors();
    sendDriveCommands(&nullDriveCmds);
    clearServos();
    return;
  } else {
    digitalWrite(LED_BLUE_B_PIN, LOW);
  }
  
  decodeRadioPacket(&packet, &throttle, &des);
  // Serial.print("YAW ");
  // Serial.println(des.yaw);
  // Serial.print("PITCH ");
  // Serial.println(des.pitch);
  // Serial.print("ROLL ");
  // Serial.println(des.roll);

  if (packet.isAutoMode) {
    autoMode();
  } else {
    teleopMode();
  }
  limitLoopRate();
}

void autoMode(void) {
  // readAllUltrasonic();
  ultrasonicCentimeters[US_FRONT_IDX] = usToCentimeters(readUltrasonicAveraged(US_FRONT_IDX));
  if (lastVehicleMode == FLIGHT_MODE) {
    uint32_t autoTimeElapsed = millis() - autoFlightStartTimeMs;
    if (autoTimeElapsed < AUTO_FLIGHT_TIMEOUT_MS) {
      transitionModeServos(FLIGHT_MODE, true);
      flyCmds.backLeft = 0.2f;
      flyCmds.backRight = 0.2f;
      flyCmds.frontLeft = 0.3f;
      flyCmds.frontRight = 0.3f;
      sendFlightCommands(&flyCmds);
      sendDriveCommands(&nullDriveCmds);
    } else {
      clearFlightMotors();
      delay(AUTO_TRANSITION_DELAY_MS);
      transitionModeServos(DRIVE_MODE, true);
    }
    sendDriveCommands(&nullDriveCmds);
  } else if (lastVehicleMode == DRIVE_MODE) {
    transitionModeServos(DRIVE_MODE, true);
    if (ultrasonicCentimeters[US_FRONT_IDX] >= FRONT_OBSTACLE_THRESH_CM) {
      driveCmds.left = 255;
      driveCmds.right = 255;
      sendDriveCommands(&driveCmds);
      clearFlightMotors();
    } else {
      sendDriveCommands(&nullDriveCmds);
      transitionModeServos(FLIGHT_MODE, true);
      delay(AUTO_TRANSITION_DELAY_MS);
      autoFlightStartTimeMs = millis();
    }
  }
}

void teleopMode(void) {
  transitionModeServos(packet.vehicleMode, false);
  if (packet.vehicleMode == FLIGHT_MODE) {
    controlRATE(&imuData, &des, throttle, &pid);
    controlMixer(&pid, throttle, &flyCmds);
    constrainFlightCommands(&flyCmds);
    // float control = packet.leftJoystickY < 512 ? 0 : ((packet.leftJoystickY - 512.0f) / 512.0f);
    // flyCmds.frontLeft = control;
    // flyCmds.frontRight = control;
    // flyCmds.backLeft = control;
    // flyCmds.backRight = control;
    sendFlightCommands(&flyCmds);
    // delayMicroseconds(100000);
      // Serial.println("COMMANDS");
      // Serial.print("FL: ");
      // Serial.println(flyCmds.frontLeft);
      // Serial.print("FR: ");
      // Serial.println(flyCmds.frontRight);
      // Serial.print("BL: ");
      // Serial.println(flyCmds.backLeft);
      // Serial.print("BR: ");
      // Serial.println(flyCmds.backRight);
      // sendDriveCommands(&nullDriveCmds);
    // delayMicroseconds(100000);
  } else {
    tankDrive(packet.leftJoystickY, packet.rightJoystickY, &driveCmds);
    clearFlightMotors();
    sendDriveCommands(&driveCmds);
  }
}

void decodeRadioPacket(RadioPacket *packet, float *throttle, RPYAngles *des) {
  *throttle = zeroCenteredJoystick(packet->leftJoystickY, LEFT_JS_Y_CTR, true);
  des->yaw = zeroCenteredJoystick(packet->leftJoystickX, LEFT_JS_X_CTR, false) * maxYaw;
  des->pitch = zeroCenteredJoystick(packet->rightJoystickY, RIGHT_JS_Y_CTR, false) * maxPitch;
  des->roll = zeroCenteredJoystick(packet->rightJoystickX, RIGHT_JS_X_CTR, false) * maxRoll;
}

inline float zeroCenteredJoystick(uint16_t value, float center, bool strictlyPositive) {
  return (value < center && strictlyPositive) ? 0 : ((value - center) / center);
}

void readAllUltrasonic(void) {
  uint32_t ch;
  for (ch = 0; ch < NUM_US; ++ch) {
    ultrasonicCentimeters[ch] = usToCentimeters(readUltrasonicAveraged(ch));
  }
}

void transitionModeServos(vehicle_mode_t vehicleMode, bool override) {
  if (override || lastVehicleMode != vehicleMode) {
    setServos(vehicleMode);
    lastVehicleMode = vehicleMode;
  }
}

void setServos(vehicle_mode_t vehicleMode) {
  if (vehicleMode == FLIGHT_MODE) {
    transitionServos[0].write(LEFT_SERVO_FLIGHT_DEG);
    transitionServos[1].write(RIGHT_SERVO_FLIGHT_DEG);
  } else {
    transitionServos[0].write(LEFT_SERVO_DRIVE_DEG);
    transitionServos[1].write(RIGHT_SERVO_DRIVE_DEG);
  }
}

void clearServos(void) {
  uint32_t ch;
  for (ch = 0; ch < NUM_TSERVO; ++ch) {
    transitionServos[ch].detach();
  }
}

void constrainFlightCommands(FlyCommands *cmds) {
 float maxCmd = max(max(max(cmds->frontLeft, cmds->frontRight), cmds->backLeft), cmds->backRight);
 if (maxCmd > 1.0f) {
  cmds->frontLeft /= maxCmd;
  cmds->frontRight /= maxCmd;
  cmds->backLeft /= maxCmd;
  cmds->backRight /= maxCmd;
 }
}

void sendFlightCommands(FlyCommands *cmds) {
  float cmd;
  const uint32_t range = MAX_MOTOR_US - MIN_MOTOR_US;
  for (uint32_t ch = 0; ch < NUM_FLY_MOTORS; ++ch) {
    cmd = *(&cmds->frontLeft + ch);
    flyMotorServos[ch].writeMicroseconds(MIN_MOTOR_US + (range * cmd));
  }
}

void clearFlightMotors(void) {
  for (uint32_t ch = 0; ch < NUM_FLY_MOTORS; ++ch) {
    flyMotorServos[ch].writeMicroseconds(0);
  }
}

void sendDriveCommands(DriveCommands *cmds) {
  uint8_t cmd;
  for (uint32_t ch = 0; ch < NUM_DRIVE_MOTORS; ++ch) {
    cmd = *(&cmds->left + ch);
    analogWrite(DRIVE_MOTOR_PINS[ch], cmd);
  }
}

void displayDebugIndicators(void) {
  bool lowVoltage = readBatteryVoltage() < V_BAT_WARN_THRESH;
  digitalWrite(LED_BLUE_A_PIN, lowVoltage);
}

float readBatteryVoltage(void) {
  uint32_t batReading = analogRead(V_BAT_PIN);
  return (batReading * VCC) / (ADC_MAX * V_BAT_DIV_RATIO) - V_BAT_OFFSET;
}

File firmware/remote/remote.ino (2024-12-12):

#include <nRF24L01.h>
#include <RF24.h>

#include "util.h"

RF24 radio(RADIO_CE_PIN, RADIO_CSN_PIN);

RadioPacket packet;

void setup() {
  Serial.begin(115200);

  /* Initialize radio to transmit/write */
  radio.begin();
  radio.setPALevel(RF24_PA_HIGH);
  radio.setChannel(RADIO_CH);
  radio.openWritingPipe(RADIO_ADDR);

  /* Set all non-radio pins to INPUT */
  pinMode(LEFT_JS_X_PIN, INPUT);
  pinMode(LEFT_JS_Y_PIN, INPUT);
  pinMode(LEFT_JS_SEL_PIN, INPUT);

  pinMode(RIGHT_JS_X_PIN, INPUT);
  pinMode(RIGHT_JS_Y_PIN, INPUT);
  pinMode(RIGHT_JS_SEL_PIN, INPUT);

  pinMode(FLIGHT_MODE_SW_PIN, INPUT);
  pinMode(AUTO_MODE_SW_PIN, INPUT);
  pinMode(BTN_ONE_PIN, INPUT);
  pinMode(BTN_TWO_PIN, INPUT);
  pinMode(BTN_THREE_PIN, INPUT);
}

void loop() {
  /* Read inputs and construct radio packet */
  packet.leftJoystickX = 1023 - analogRead(LEFT_JS_X_PIN);
  packet.leftJoystickY = 1023 - analogRead(LEFT_JS_Y_PIN);
  packet.leftJoystickSelect = digitalRead(LEFT_JS_SEL_PIN);

  packet.rightJoystickX = 1023 - analogRead(RIGHT_JS_X_PIN);
  packet.rightJoystickY = 1023 - analogRead(RIGHT_JS_Y_PIN);
  packet.rightJoystickSelect = digitalRead(RIGHT_JS_SEL_PIN);

  packet.vehicleMode = digitalRead(FLIGHT_MODE_SW_PIN);
  packet.isAutoMode = digitalRead(AUTO_MODE_SW_PIN);
  packet.buttonOne = digitalRead(BTN_ONE_PIN);
  packet.buttonTwo = digitalRead(BTN_TWO_PIN);
  packet.buttonThree = digitalRead(BTN_THREE_PIN);

  /* Write radio packet */
  radio.write(&packet, sizeof(packet));
  /* Do not delay after sending as vehicle loop time is very fast */
  // delay(100);
  // printPacket(&packet);
  // Serial.print("Radio Connected: ");
  // Serial.println(radio.isChipConnected());
}

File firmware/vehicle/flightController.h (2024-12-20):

#ifndef FLIGHTCONTROLLER_H
#define FLIGHTCONTROLLER_H

#include "util.h"

const float MIN_THROTTLE = 0.2; //Minimum throttle to effect output, in raw packet units

//Filter parameters - Defaults tuned for 2kHz loop rate; Do not touch unless you know what you are doing:
const float B_madgwick = 0.04;      //Madgwick filter parameter

//Controller parameters (take note of defaults before modifying!): 
const float i_limit = 25.0;         //Integrator saturation level, mostly for safety (default 25.0)
const float maxRoll = 10.0;         //Max roll angle in degrees for angle mode (maximum ~70 degrees), deg/sec for rate mode 
const float maxPitch = 10.0;        //Max pitch angle in degrees for angle mode (maximum ~70 degrees), deg/sec for rate mode
const float maxYaw = 10.0;         //Max yaw rate in deg/sec

const float Kp_roll = 5;          //Roll P-gain - angle mode 
const float Ki_roll = 0.0;          //Roll I-gain - angle mode
const float Kd_roll = 2;         //Roll D-gain - angle mode (has no effect on controlANGLE2)
const float Kp_pitch = 5;         //Pitch P-gain - angle mode
const float Ki_pitch = 0.0;         //Pitch I-gain - angle mode
const float Kd_pitch = 2;        //Pitch D-gain - angle mode (has no effect on controlANGLE2)
const float Kp_yaw = 5;           //Yaw P-gain
const float Ki_yaw = 0.0;          //Yaw I-gain
const float Kd_yaw = 2;       //Yaw D-gain (be careful when increasing too high, motors will begin to overheat!)

/** Initialize flight controller constants. */
void initConstants(void);

/**
 * DESCRIPTION: Attitude estimation through sensor fusion - 6DOF
 * 
 * See description of Madgwick() for more information. This is a 6DOF implimentation for when magnetometer data is not
 * available (for example when using the recommended MPU6050 IMU for the default setup).
 */
void Madgwick6DOF(IMUData *imu, RPYAngles *angles);

/**
 * DESCRIPTION: Computes control commands based on state error (angle)
 * 
 * Basic PID control to stablize on angle setpoint based on desired states roll_des, pitch_des, and yaw_des computed in 
 * getDesState(). Error is simply the desired state minus the actual state (ex. roll_des - roll_IMU). Two safety features
 * are implimented here regarding the I terms. The I terms are saturated within specified limits on startup to prevent 
 * excessive buildup. This can be seen by holding the vehicle at an angle and seeing the motors ramp up on one side until
 * they've maxed out throttle...saturating I to a specified limit fixes this. The second feature defaults the I terms to 0
 * if the throttle is at the minimum setting. This means the motors will not start spooling up on the ground, and the I 
 * terms will always start from 0 on takeoff. This function updates the variables pid->roll, pid->pitch, and pid->yaw which
 * can be thought of as 1-D stablized signals. They are mixed to the configuration of the vehicle in controlMixer().
 */
void controlANGLE(IMUData *imu, RPYAngles *actual, RPYAngles *des, float throttle, RPYAngles *pid);

void controlRATE(IMUData *imu, RPYAngles *des, float throttle, RPYAngles *pid);

/**
 * Mix PID'd RPY/YPR and throttle into motor commands
 * 
 * @param pid PID'd RPY/YPR control values
 * @param throttle controlled throttle value
 * @param cmds pointer to MotorCommands to set (output)
 */
void controlMixer(RPYAngles *pid, float throttle, FlyCommands *cmds);

/**
 * Inverse square root utility function
 * 
 * sqrt(...) function is used since Teensy has enough overhead.
 * Can be changed to be more approximate if performance is limited.
 * 
 * @param value float to take the square root of
 * @return 1 / sqrt(value) 
 */
inline float invSqrt(float value) {
  return 1.0 / sqrt(value);
}

#endif /* FLIGHTCONTROLLER_H */

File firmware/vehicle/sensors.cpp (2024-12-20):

#include "sensors.h"

uint32_t avgAccs[NUM_US] = {};
uint32_t avgIdxs[NUM_US] = {};
uint32_t avgBufs[NUM_US][WINDOW_SIZE] = {};

Adafruit_MPU6050 imu;
Adafruit_Sensor *imuAccel;
Adafruit_Sensor *imuGyro;
sensors_event_t sensorEvent;
IMUData *prevImuData;

uint32_t movingAverage(uint32_t value, uint32_t *buffer, uint32_t *accumulator, uint32_t *index) {
  *accumulator -= buffer[*index];         // Remove the oldest entry from the sum
  buffer[*index] = value;                 // Add the newest reading to the window
  *accumulator += value;                  // Add the newest reading to the sum
  *index = (*index + 1) % WINDOW_SIZE;    // Increment the index, and wrap to 0 if it exceeds the window size
  return *accumulator / WINDOW_SIZE; 
}

// float movingAverageFloat(float value, float *buffer, float *accumulator, uint32_t *index) {
//   *accumulator -= buffer[*index];         // Remove the oldest entry from the sum
//   buffer[*index] = value;                 // Add the newest reading to the window
//   *accumulator += value;                  // Add the newest reading to the sum
//   *index = (*index + 1) % WINDOW_SIZE_FLOAT;    // Increment the index, and wrap to 0 if it exceeds the window size
//   return *accumulator / WINDOW_SIZE_FLOAT; 
// }

uint32_t readUltrasonicAveraged(uint32_t ch) {
  uint32_t us = readUltrasonicRaw(ch);
  return movingAverage(us, avgBufs[ch], &avgAccs[ch], &avgIdxs[ch]);
}

uint32_t readUltrasonicRaw(uint32_t ch) {
  digitalWrite(US_TRIG[ch], LOW);
  delayMicroseconds(2);  /* Ensure pin is reset */
  digitalWrite(US_TRIG[ch], HIGH);
  delayMicroseconds(10);  /* 10us delay to start module */
  digitalWrite(US_TRIG[ch], LOW);
  return pulseIn(US_ECHO[ch], HIGH);
}

void initIMU(TwoWire *wire) {
  imu = Adafruit_MPU6050();

  imu.begin(MPU6050_I2CADDR_DEFAULT, wire);
  imu.setFilterBandwidth(LPF_BW);
  imu.setGyroRange(GYRO_SCALE);
  imu.setAccelerometerRange(ACCEL_SCALE);

  imuAccel = imu.getAccelerometerSensor();
  imuGyro = imu.getGyroSensor();
}

void calibrateIMU(IMUData *error) {
  IMUData nextData;
  uint32_t i;
  for(i = 0; i < NUM_IMU_CALIBRATION_ITER; i++) {
    readIMU(&nextData);
    addIMUData(error, &nextData);
  }
  divIMUData(error, NUM_IMU_CALIBRATION_ITER);
}

// #define IMU_DATA_IDXS 6
// float avgImuAccs[IMU_DATA_IDXS] = {};
// uint32_t avgImuIdxs[IMU_DATA_IDXS] = {};
// float avgImuBufs[IMU_DATA_IDXS][WINDOW_SIZE] = {};

void readIMU(IMUData *data) {
  imuAccel->getEvent(&sensorEvent);
  data->accX = -sensorEvent.acceleration.x;
  data->accY = -sensorEvent.acceleration.y;
  data->accZ = -sensorEvent.acceleration.z;
  // data->accX = movingAverageFloat(-sensorEvent.acceleration.x, avgImuBufs[0], &avgImuAccs[0], &avgImuIdxs[0]);
  // data->accY = movingAverageFloat(-sensorEvent.acceleration.y, avgImuBufs[1], &avgImuAccs[1], &avgImuIdxs[1]);
  // data->accZ = movingAverageFloat(-sensorEvent.acceleration.z, avgImuBufs[2], &avgImuAccs[2], &avgImuIdxs[2]);

  imuGyro->getEvent(&sensorEvent);
  data->gyrX = sensorEvent.gyro.x;
  data->gyrY = sensorEvent.gyro.y;
  data->gyrZ = sensorEvent.gyro.z;
  // data->gyrX = movingAverageFloat(sensorEvent.gyro.x, avgImuBufs[3], &avgImuAccs[3], &avgImuIdxs[3]);
  // data->gyrY = movingAverageFloat(sensorEvent.gyro.y, avgImuBufs[4], &avgImuAccs[4], &avgImuIdxs[4]);
  // data->gyrZ = movingAverageFloat(sensorEvent.gyro.z, avgImuBufs[5], &avgImuAccs[5], &avgImuIdxs[5]);
}

void addIMUData(IMUData *a, IMUData *b) {
  a->accX += b->accX;
  a->accY += b->accY;
  a->accZ += b->accZ;

  a->gyrX += b->gyrX;
  a->gyrY += b->gyrY;
  a->gyrZ += b->gyrZ;
}

void subIMUData(IMUData *a, IMUData *b) {
  a->accX -= b->accX;
  a->accY -= b->accY;
  a->accZ -= b->accZ;

  a->gyrX -= b->gyrX;
  a->gyrY -= b->gyrY;
  a->gyrZ -= b->gyrZ;
}

void divIMUData(IMUData *data, uint32_t k) {
  data->accX /= k;
  data->accY /= k;
  data->accZ /= k;

  data->gyrX /= k;
  data->gyrY /= k;
  data->gyrZ /= k;
}

void printIMU(IMUData *data) {
  Serial.println("IMU DATA");
  
  Serial.print("Acceleration X: ");
  Serial.println(data->accX);
  Serial.print("Acceleration Y: ");
  Serial.println(data->accY);
  Serial.print("Acceleration Z: ");
  Serial.println(data->accZ);

  Serial.print("Gyroscope X: ");
  Serial.println(data->gyrX);
  Serial.print("Gyroscope Y: ");
  Serial.println(data->gyrY);
  Serial.print("Gyroscope Z: ");
  Serial.println(data->gyrZ);
}

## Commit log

2024-10-22 Implement ultrasonic sensor read in fw
2024-10-23 Add IMU initialization and reading
2024-11-06 Add toroidal propeller CAD
    [toroidal_propeller.stl]
2024-11-06 Separate drive servos from fly motors
2024-11-06 Extract ultrasonic sensor into sensor.c/.h
2024-12-05 Resolve compile errors and convert IMU to MPU6050
    [flightController.h, remote.ino, sensors.cpp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]
2024-12-05 Add servo vehicle mode control
2024-12-06 Refactor servo constants and radio print function
2024-12-10 All four fly motors spinning and IMU reading
2024-12-12 Debugging YPR PID controller
2024-12-12 Velocity PID controller on fly YPR
2024-12-20 Add all CAD files
    [Assembly 2.step, Assembly 3.step, Assembly 6.step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]
2024-12-20 Refactor into ecad/mcad
    [Assembly 2.step, Assembly 3.step, Assembly 6.step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]
2024-12-20 Add all Altium ECAD
    [STEP_[No Variations] for Remote.PcbDoc.step]
